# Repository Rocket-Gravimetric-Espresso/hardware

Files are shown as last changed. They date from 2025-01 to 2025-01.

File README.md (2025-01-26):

# Hardware

Custom PCB for the Rocket Gravimetric Espresso project, designed in KiCad 8. The board is powered via 5V USB-C on the XIAO module.

## Components

| Ref | Part | Description |
|-----|---|---|
| U1 | [Seeed XIAO nRF52840](https://wiki.seeedstudio.com/XIAO_BLE/) | MCU (I2C, SPI) |
| U2 | [NAU7802SGI](https://www.nuvoton.com/resource-files/NAU7802%20Data%20Sheet%20V1.7.pdf) | 24-bit ADC |
| U3 | [TCK108AF](https://toshiba.semicon-storage.com/info/TCK108AF_datasheet_en_20151229.pdf?did=53240&prodName=TCK108AF) | Load switch for pump control |
| J1 | 4-pin terminal block | [TAL221 500g load cell](https://cdn.sparkfun.com/assets/9/9/a/f/3/TAL221.pdf) connection |
| J3, J4 | 20-pin headers | SPI and I2C breakout for the ([Adafruit 2.8" TFT](https://www.adafruit.com/product/2090)) |

## PCB Layout

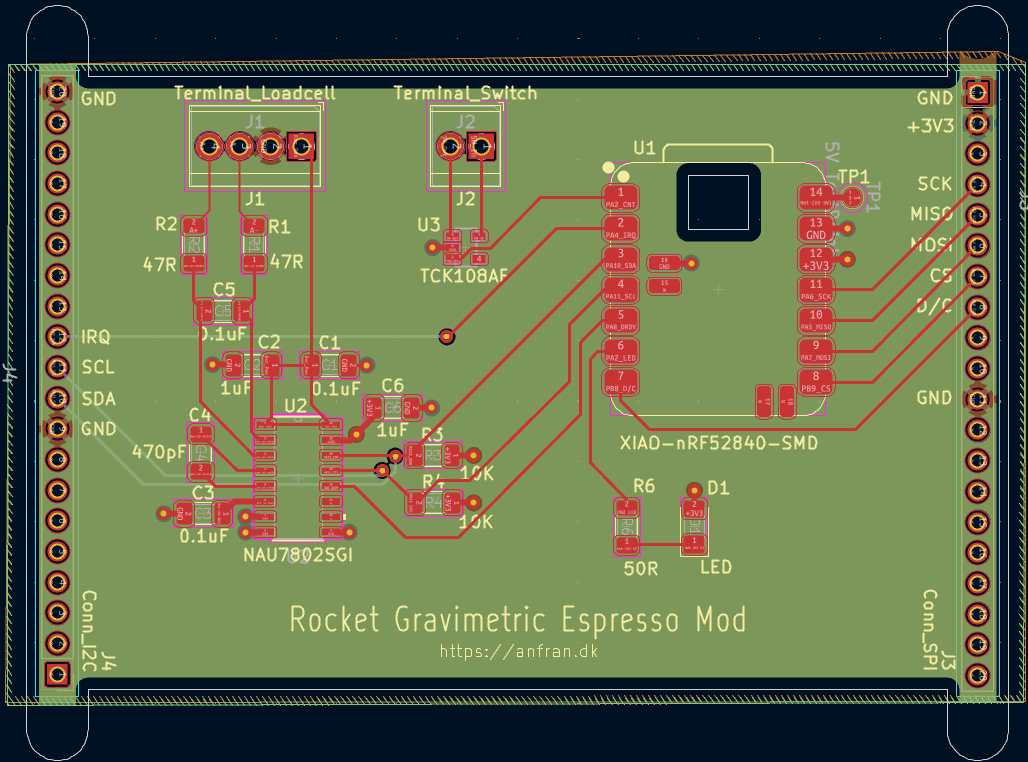
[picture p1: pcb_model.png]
PCB layout


## Soldered Board

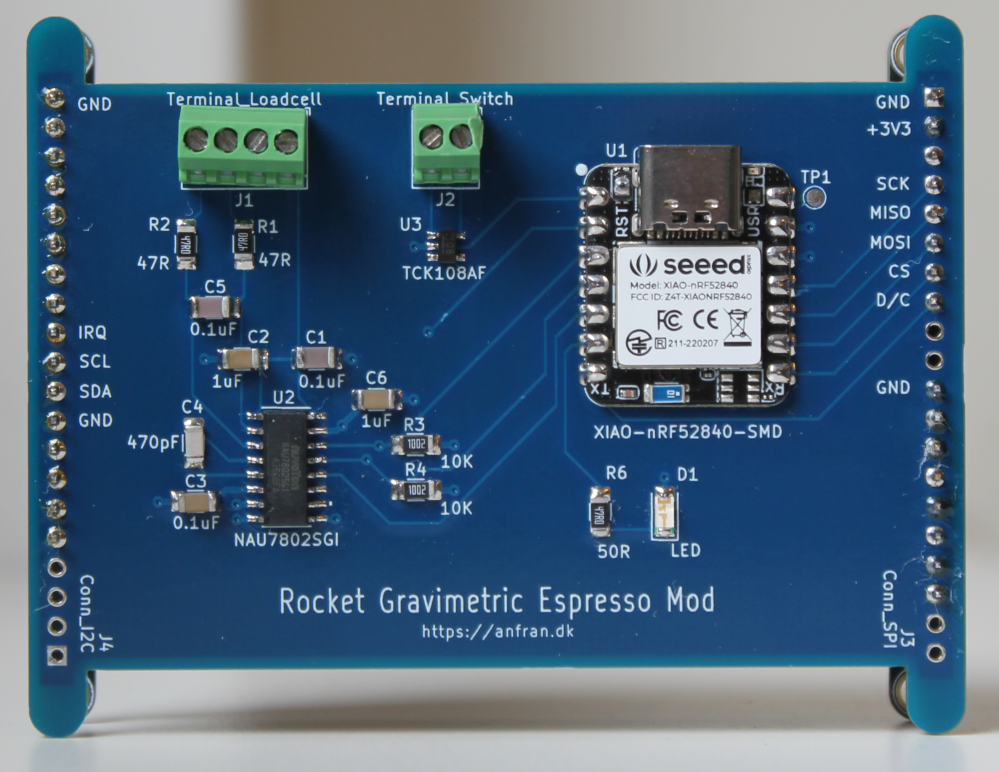
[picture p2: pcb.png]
Soldered PCB


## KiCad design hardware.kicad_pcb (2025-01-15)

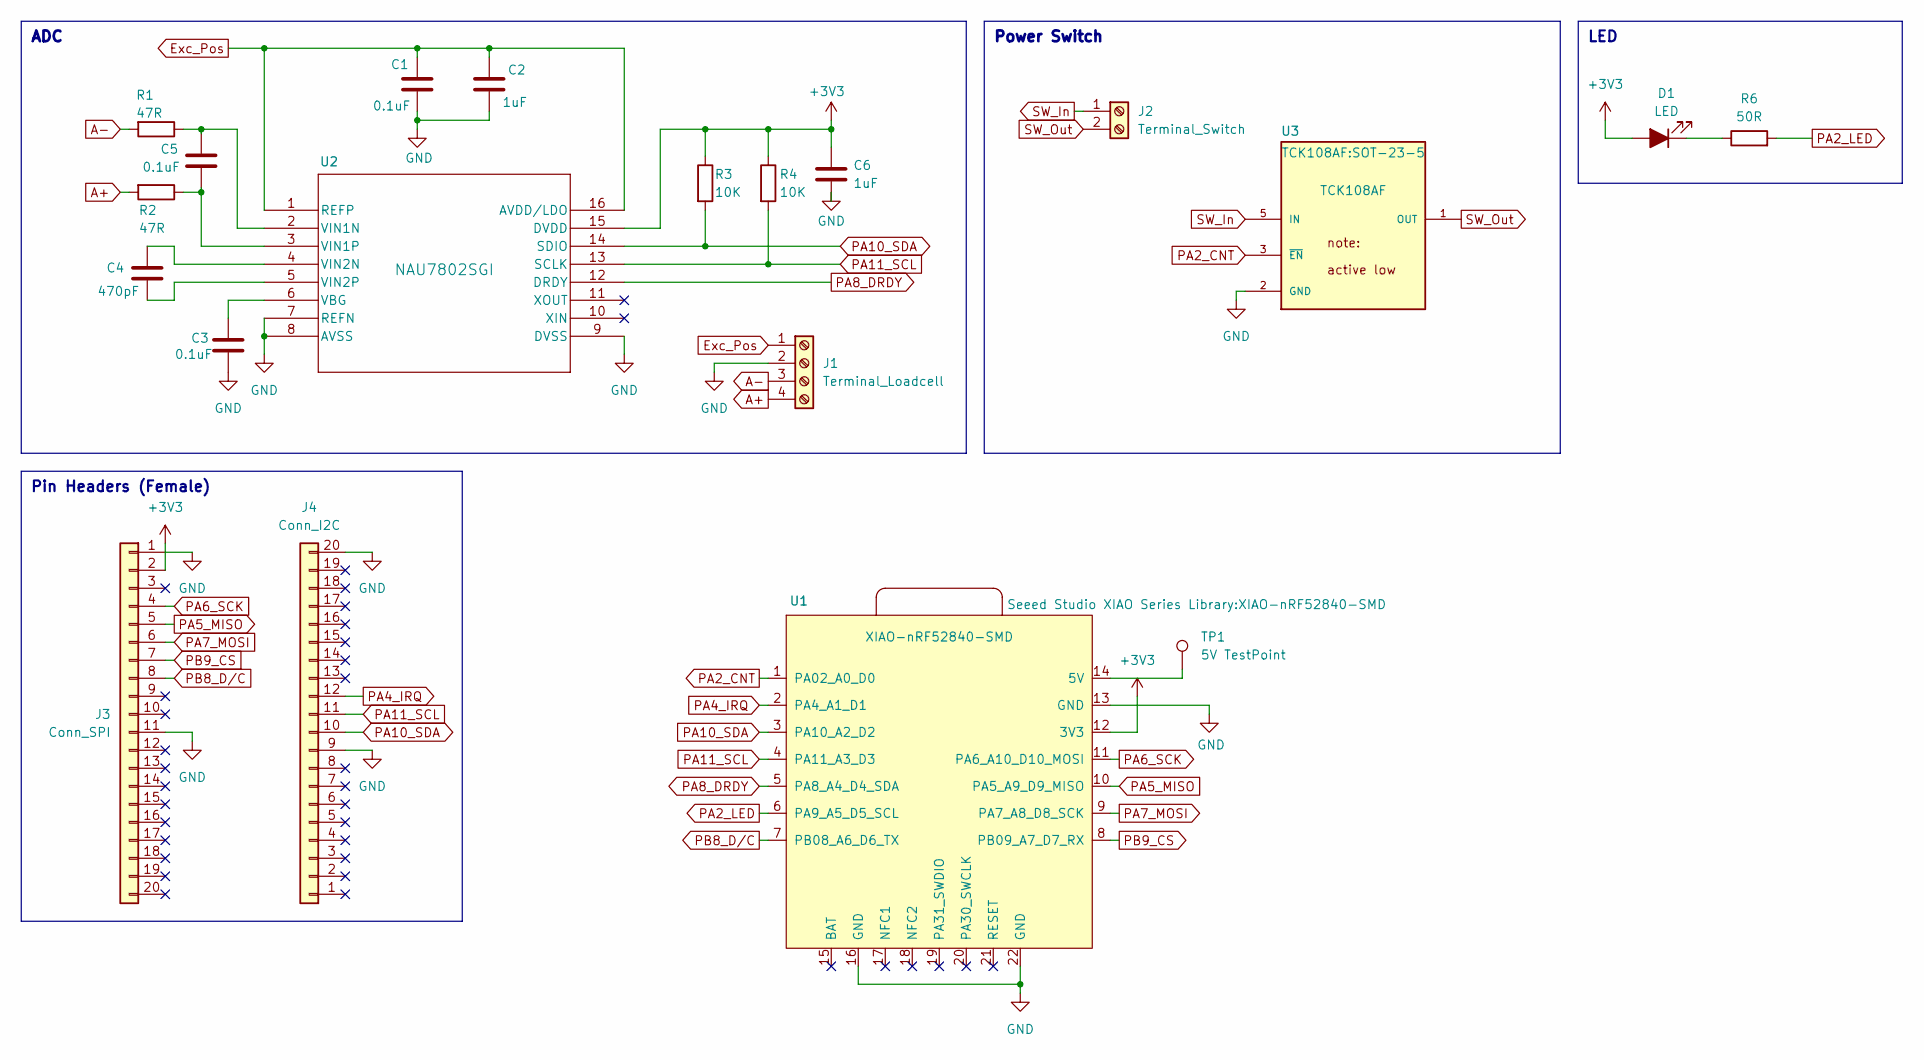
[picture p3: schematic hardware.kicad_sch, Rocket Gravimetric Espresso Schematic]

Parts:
C1, C3, C5: 0.1uF; C_1206_3216Metric_Pad1.33x1.80mm_HandSolder
C2, C6: 1uF; C_1206_3216Metric_Pad1.33x1.80mm_HandSolder
C4: 470pF; C_1206_3216Metric_Pad1.33x1.80mm_HandSolder
D1: LED; LED_1206_3216Metric_Pad1.42x1.75mm_HandSolder
J1: Terminal_Loadcell; TerminalBlock_TE_282834-4_1x04_P2.54mm_Horizontal
J2: Terminal_Switch; TerminalBlock_TE_282834-2_1x02_P2.54mm_Horizontal
J3: Conn_SPI; PinSocket_1x20_P2.54mm_Vertical
J4: Conn_I2C; PinSocket_1x20_P2.54mm_Vertical
R1, R2: 47R; R_1206_3216Metric_Pad1.30x1.75mm_HandSolder
R3, R4: 10K; R_1206_3216Metric_Pad1.30x1.75mm_HandSolder
R6: 50R; R_1206_3216Metric_Pad1.30x1.75mm_HandSolder
TP1: 5V TestPoint; TestPoint_Pad_D1.5mm
U1: XIAO-nRF52840-SMD
U2: NAU7802SGI; SOI16_NAU7802SGI_NUV
U3: TCK108AF; SOT-23-5

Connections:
+3V3: C6.1, D1.2 (A), J3.2, R3.1, R4.1, U1.12 (3V3), U2.15 (DVDD)
A+: J1.4, R2.2
A-: J1.3, R1.2
Exc_Pos: C1.1, C2.1, J1.1, U2.1 (REFP), U2.16 (AVDD/LDO)
GND: C1.2, C2.2, C3.2, C6.2, J1.2, J3.1, J3.11, J4.9, J4.20, U1.13 (GND), U1.16 (GND), U1.22 (GND), U2.7 (REFN), U2.8 (AVSS), U2.9 (DVSS), U3.2 (GND)
unnamed: D1.1 (K), R6.1
unnamed: TP1.1, U1.14 (5V)
unnamed: C3.1, U2.6 (VBG)
unnamed: C5.1, R1.1, U2.2 (VIN1N)
unnamed: C5.2, R2.1, U2.3 (VIN1P)
unnamed: C4.1, U2.4 (VIN2N)
unnamed: C4.2, U2.5 (VIN2P)
PA2_CNT: U1.1 (PA02_A0_D0), U3.3 (~EN)
PA2_LED: R6.2, U1.6 (PA9_A5_D5_SCL)
PA4_IRQ: J4.12, U1.2 (PA4_A1_D1)
PA5_MISO: J3.5, U1.10 (PA5_A9_D9_MISO)
PA6_SCK: J3.4, U1.11 (PA6_A10_D10_MOSI)
PA7_MOSI: J3.6, U1.9 (PA7_A8_D8_SCK)
PA8_DRDY: U1.5 (PA8_A4_D4_SDA), U2.12 (DRDY)
PA10_SDA: J4.10, R3.2, U1.3 (PA10_A2_D2), U2.14 (SDIO)
PA11_SCL: J4.11, R4.2, U1.4 (PA11_A3_D3), U2.13 (SCLK)
PB8_D/C: J3.8, U1.7 (PB08_A6_D6_TX)
PB9_CS: J3.7, U1.8 (PB09_A7_D7_RX)
SW_In: J2.1, U3.5 (IN)
SW_Out: J2.2, U3.1 (OUT)

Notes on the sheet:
Power Switch
LED
ADC
Pin Headers (Female)

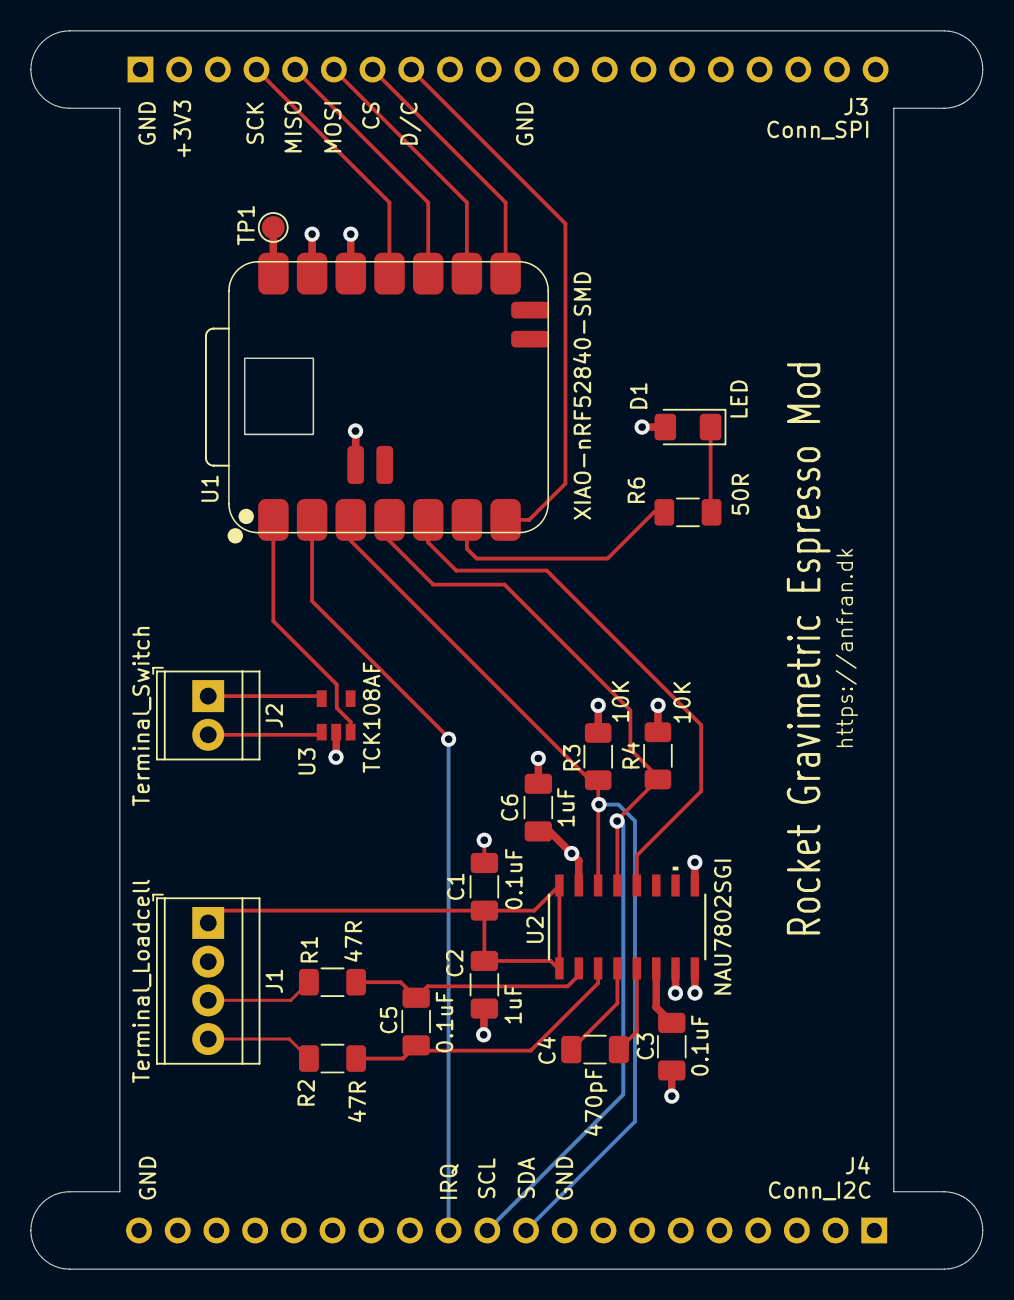
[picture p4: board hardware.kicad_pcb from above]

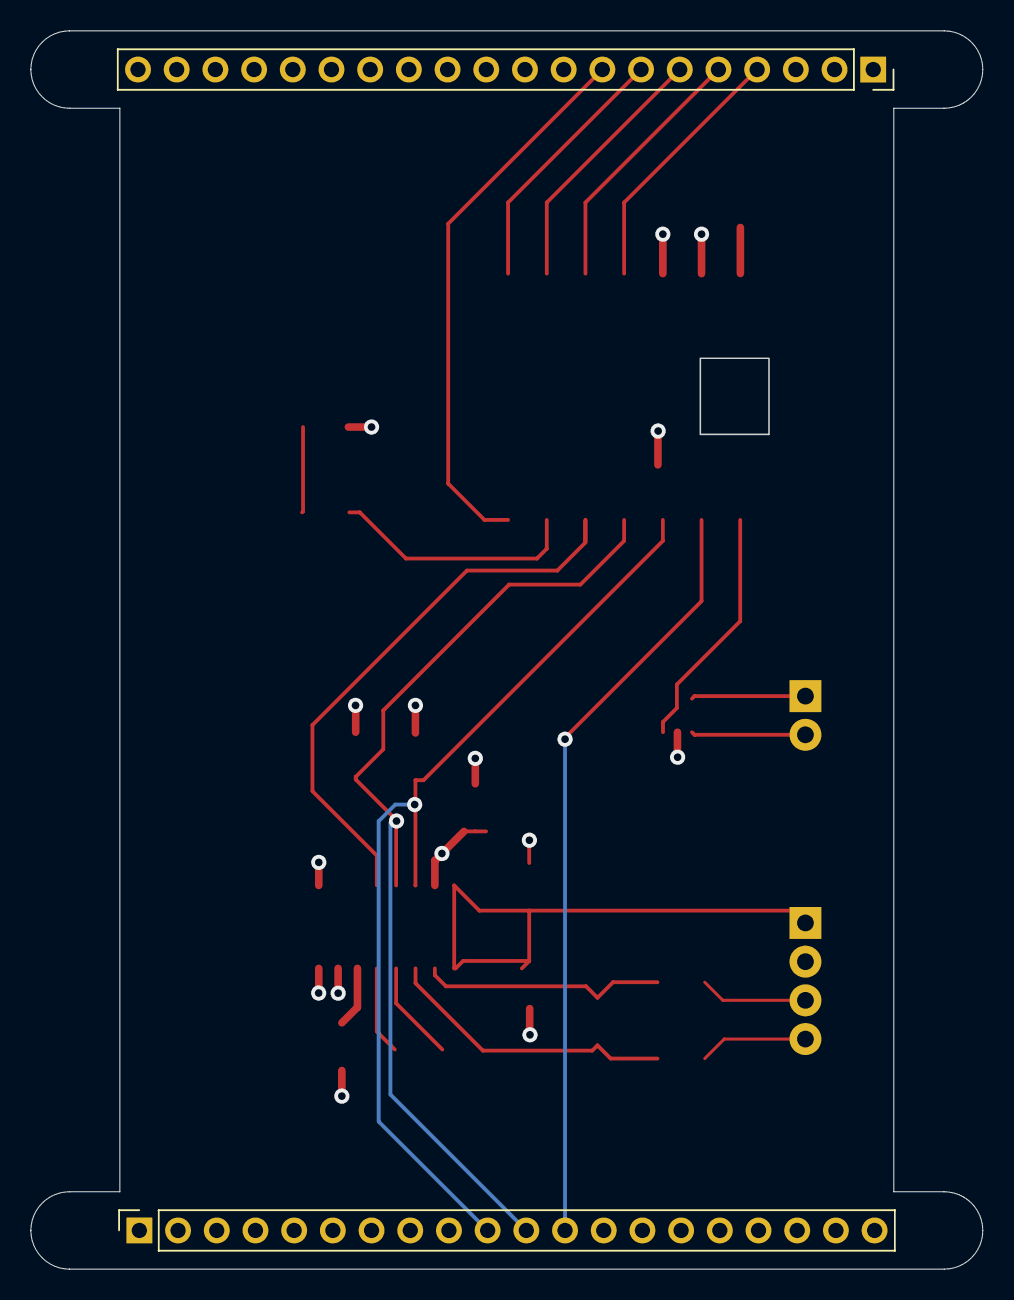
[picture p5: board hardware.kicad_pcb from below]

Board: 4 copper layers, 62.5 x 81.3 mm, 20 parts (2 on the bottom side), 25 nets.

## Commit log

2024-11-18 Initial commit: KiCAD project
    [hardware.kicad_pcb, hardware.kicad_sch]
2024-12-21 schematic v0.1
    [hardware.kicad_sch]
2025-01-15 finished PCB v0.1
    [hardware.kicad_pcb, hardware.kicad_sch]
